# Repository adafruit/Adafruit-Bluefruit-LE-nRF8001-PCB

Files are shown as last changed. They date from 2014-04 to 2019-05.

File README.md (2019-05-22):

## Bluefruit LE - Bluetooth Low Energy (BLE 4.0) - nRF8001 Breakout - v1.0 PCB
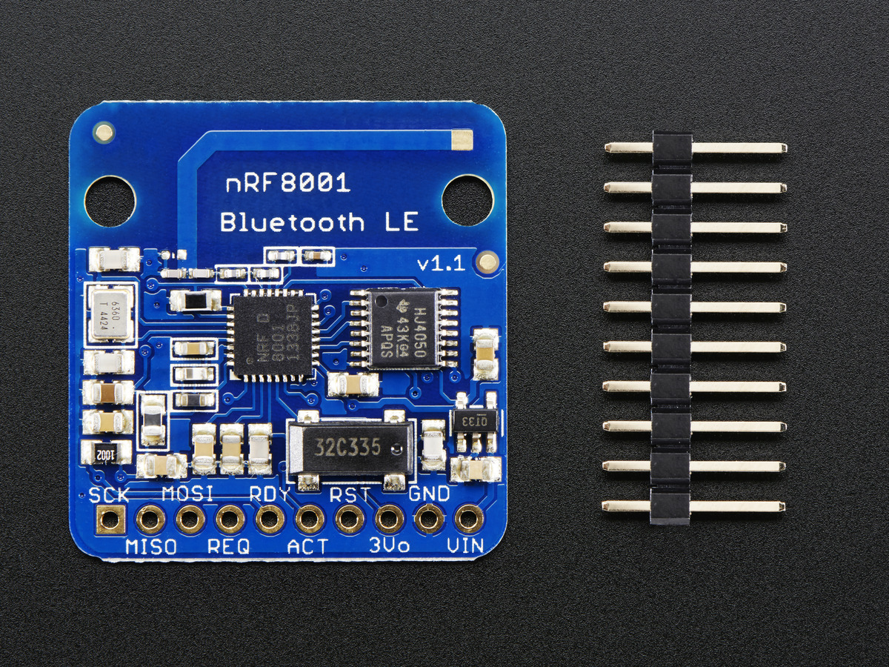
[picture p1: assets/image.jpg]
<a href="http://www.adafruit.com/products/1697"><br/>
Click here to purchase one from the Adafruit shop</a>

Our Adafruit Bluefruit LE (Bluetooth Smart, Bluetooth Low Energy, Bluetooth 4.0) nRF8001 Breakout allows you to establish an easy to use wireless link between your Arduino and any compatible iOS or Android (4.3+) device. It works by simulating a UART device beneath the surface, sending ASCII data back and forth between the devices, letting you decide what data to send and what to do with it on either end of the connection.

Unlike classic Bluetooth, BLE has no big contracts to sign and no major hoops that you have to jump through to create iOS peripherals that you can legally design and distribute in the App Store, which makes it a great choice compared to classic Bluetooth which had (and still has) a lot of restrictions around it on the iOS platform.

These are the PCB files for Adafruit Bluefruit LE nRF8001 PCB. The format is EagleCAD schematic and board layout
- https://www.adafruit.com/product/1697

### License

Adafruit invests time and resources providing this open source design, please support Adafruit and open-source hardware by purchasing products from [Adafruit](https://www.adafruit.com)!

All text above must be included in any redistribution

Designed by Limor Fried/Ladyada for Adafruit Industries.
Creative Commons Attribution/Share-Alike, all text above must be included in any redistribution. 
See license.txt for additional information.

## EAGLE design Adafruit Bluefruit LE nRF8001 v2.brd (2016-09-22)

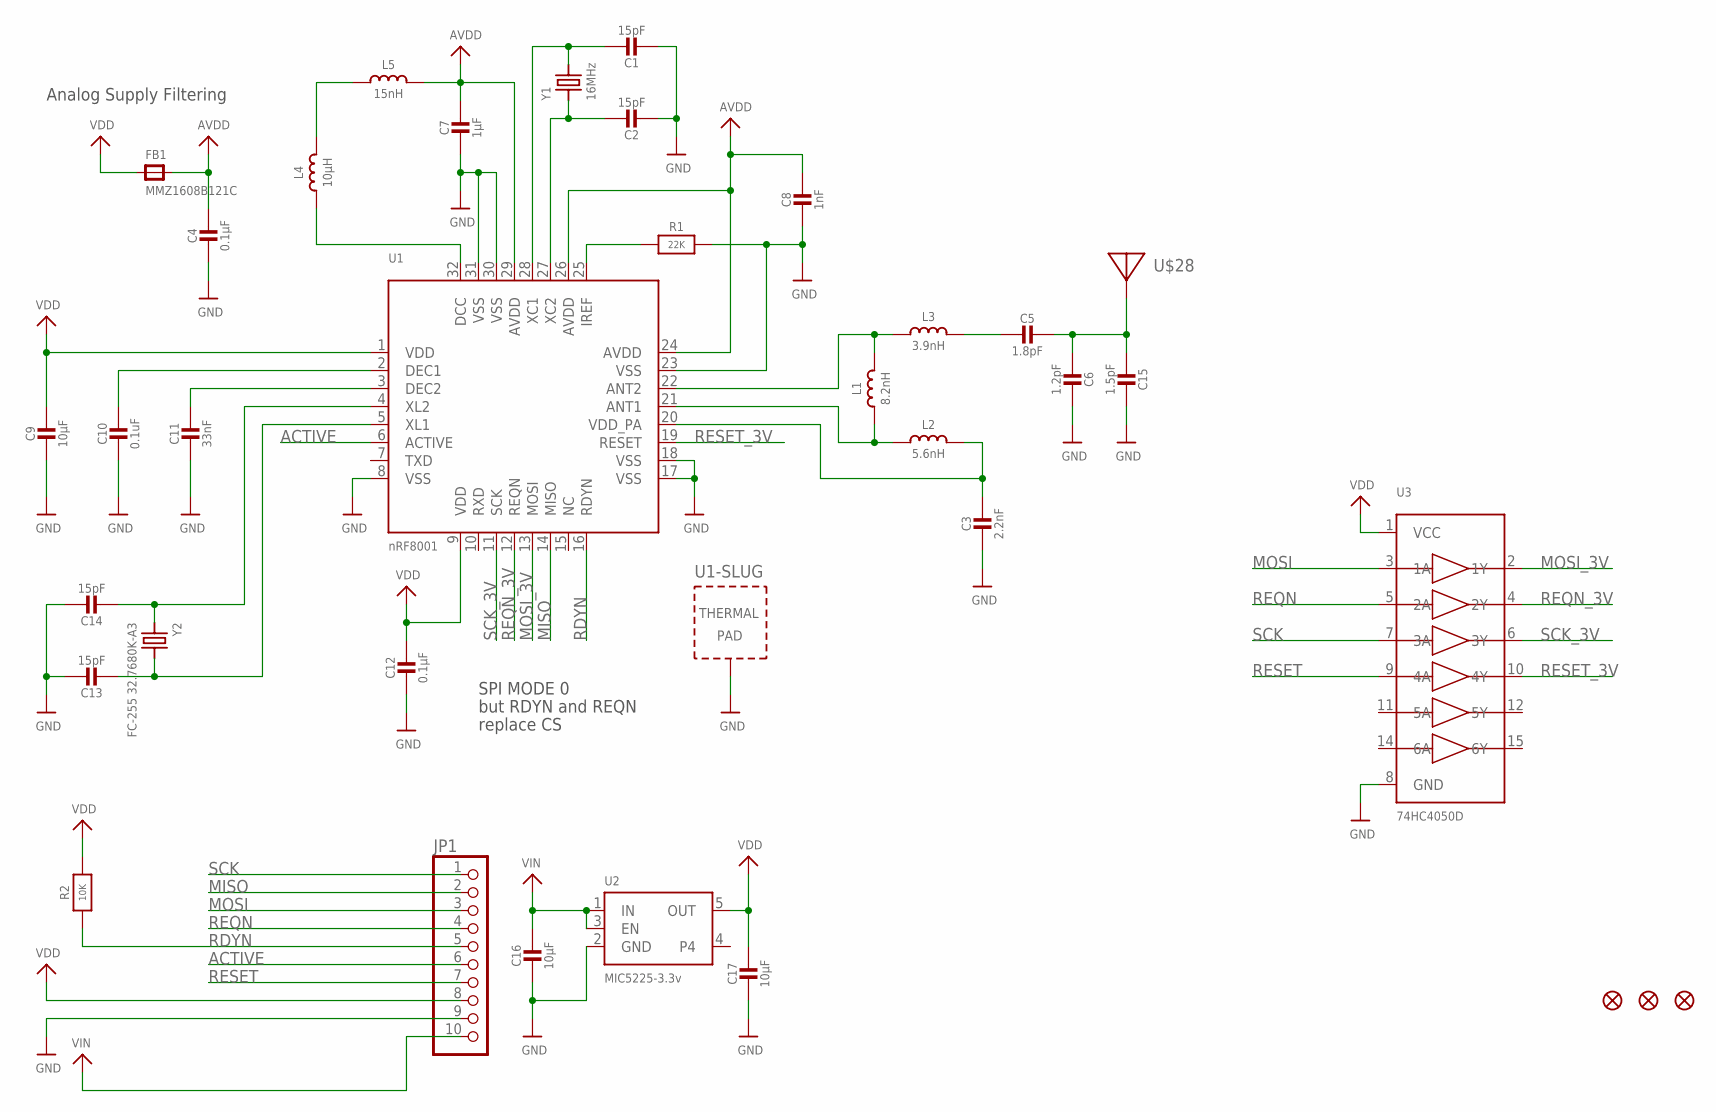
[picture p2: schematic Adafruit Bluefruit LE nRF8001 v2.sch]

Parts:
C1, C2, C13, C14: 15pF; 0805-NO
C3: 2.2nF; _0402
C4, C12: 0.1µF; 0805-NO
C5: 1.8pF; _0402MP
C6: 1.2pF; _0402MP
C7: 1µF; 0805-NO
C8: 1nF; _0603
C9, C16, C17: 10µF; 0805-NO
C10: 0.1uF; 0805-NO
C11: 33nF; 0805-NO
C15: 1.5pF; _0402MP
FB1: MMZ1608B121C; 0805
FID1, FID2, FID3: FIDUCIAL""; FIDUCIAL_1MM
JP1: HEADER-1X1070MIL; 1X10_ROUND70
L1: 8.2nH; _0402
L2: 5.6nH; _0402
L3: 3.9nH; _0402
L4: 10µH; _0603
L5: 15nH; _0603
R1: 22K; _0805MP
R2: 10K; 0805-NO
U1: nRF8001; QFN32_5MM
U2: MIC5225-3.3v; SOT23-5
U3: 74HC4050D; TSSOP16
U$28: ANTENNA_PCBNRF8001_1.6MM; ANT_PCB_2.4GHZ_NRF8001_1.6MM_1OZ
Y1: 16MHz; CRYSTAL_3.2X2.5
Y2: FC-255 32.7680K-A3; CRYSTAL_8X3.8

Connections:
+3.3V: C9.1, C12.1, C17.1, FB1.1, JP1.8, R2.2, U1.1 (VDD), U1.9 (VDD), U2.5 (OUT), U3.1 (VCC)
ACTIVE: JP1.6, U1.6 (ACTIVE)
AVDD: C4.1, C7.1, C8.1, FB1.2, L5.2, U1.24 (AVDD), U1.26 (AVDD), U1.29 (AVDD)
GND: C1.2, C2.2, C3.2, C4.2, C6.1, C7.2, C8.2, C9.2, C10.2, C11.2, C12.2, C13.1, C14.1, C15.1, C16.2, C17.2, JP1.9, R1.2, U1.8 (VSS), U1.17 (VSS), U1.18 (VSS), U1.23 (VSS), U1.30 (VSS), U1.31 (VSS), U1.33 (TP), U2.2 (GND), U3.8 (GND)
MISO: JP1.2, U1.14 (MISO)
MOSI: JP1.3, U3.3 (1A)
MOSI_3V: U1.13 (MOSI), U3.2 (1Y)
unnamed: L1.2, L3.1, U1.22 (ANT2)
unnamed: L1.1, L2.1, U1.21 (ANT1)
unnamed: C3.1, L2.2, U1.20 (VDD_PA)
unnamed: L4.2, L5.1
unnamed: C5.2, L3.2
unnamed: C11.1, U1.3 (DEC2)
unnamed: C10.1, U1.2 (DEC1)
unnamed: C1.1, U1.28 (XC1), Y1.2
unnamed: C2.1, U1.27 (XC2), Y1.1
unnamed: L4.1, U1.32 (DCC)
unnamed: R1.1, U1.25 (IREF)
unnamed: C5.1, C6.2, C15.2, U$28.FEED
unnamed: C14.2, U1.4 (XL2), Y2.P$1 (1)
unnamed: C13.2, U1.5 (XL1), Y2.P$4 (2)
RDYN: JP1.5, R2.1, U1.16 (RDYN)
REQN: JP1.4, U3.5 (2A)
REQN_3V: U1.12 (REQN), U3.4 (2Y)
RESET: JP1.7, U3.9 (4A)
RESET_3V: U1.19 (RESET), U3.10 (4Y)
SCK: JP1.1, U3.7 (3A)
SCK_3V: U1.11 (SCK), U3.6 (3Y)
VIN: C16.1, JP1.10, U2.1 (IN), U2.3 (EN)

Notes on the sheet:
Analog Supply Filtering
SPI MODE 0
but RDYN and REQN
replace CS

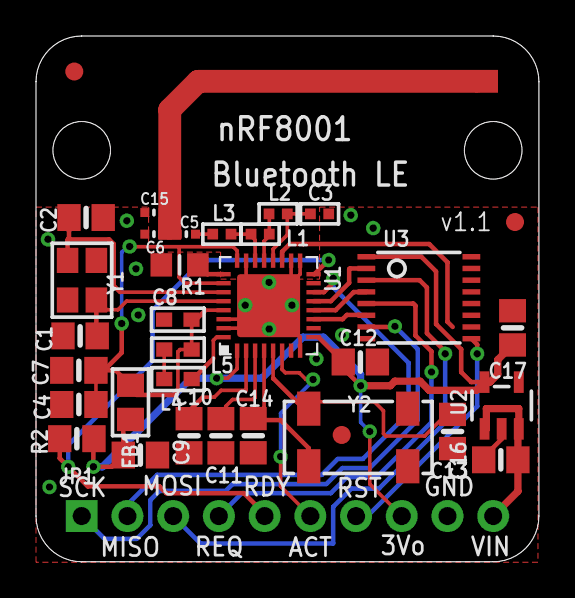
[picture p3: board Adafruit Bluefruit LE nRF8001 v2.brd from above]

Board: 2 copper layers, 27.9 x 29.2 mm, 36 parts (1 on the bottom side), 29 nets.

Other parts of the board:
U$22: ADAFRUIT_TEXT_20MM

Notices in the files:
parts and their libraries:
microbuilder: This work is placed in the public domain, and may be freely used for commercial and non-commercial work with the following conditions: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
